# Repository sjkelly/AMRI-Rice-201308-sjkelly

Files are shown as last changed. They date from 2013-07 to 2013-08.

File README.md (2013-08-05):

#AMRI @ Rice University, August 2013
This is a git repository to act as my lab notebook for my fellowship at the Advanced Manufacturing Research Institute at Rice University from August 1st to the 31st. My mentors and sponsors are professor Jordan Miller, Rice University, and Johnny Russell, UltiMachine.

## Design analysis
* [Retrosynthetic Analysis](./retrosynthetic_analysis.md)

## Inkshield Notes
Documentation describing the software exploration of the Inkshield and HPC6602 inkjet head. Also includes notes on Marlin integration.
* [Link](./inkshield_notes.md)

## Daily Objectives
My notes from morning and afternoon meetings with AMRI mentors and fellows. Briefly describes structure of experiments for the day and general objectives/housekeeping.
* [Link](./daily_objectives.md)

## Proposal
The project proposal.
* [Link](./proposal.md)

##License
All software, hardware, and documentation, unless otherwise noted is available under the MIT license. See LICENSE for details.

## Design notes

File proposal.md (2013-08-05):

#Proposal
A project proposal for the Advanced Manufacturing Research Institute.

##Objective
Experiment with convergence of ink jet print head technology and RepRap software and hardware.

##Project Outline
The goal of this project is to improve upon ink jet printing with RepRap technologies for use in the research and the DIY levels. We will achieve this by using existing open source software and hardware as the basis. The scientific method will be used throughout the process, along with an open lab notebook published to GitHub. This will ensure in the event all goals are not attained, useful data will be available to the Internet community, in the form of Git repositories.
###Hardware integration
The first stage of the project will be the integration of ink jet print heads with RepRap mechanics. This will require design of adapters to mount the ink jet heads in place of (or besides) a RepRap extrusion nozzle.
###Software integration
In order to achieve integration with RepRap software, I will focus on contributing to existing projects as much as possible. On the control side of the RepRap, we can leverage Marlin as a development base. On the host side, it will be necessary to build software to handle generation of nozzle firing sequences.
###Electronics Integration
UltiMachine has funded the purchase of 6 InkShields and 11 ink jet heads for this project. I will use RAMBo as a controller base, but design all software to be applicable to any controller with enough extra output pins.

##Existing Solutions

##Applications

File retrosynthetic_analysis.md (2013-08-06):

#Retrosynthetic Analysis
Jordan Miller introduced me to this technique. The wikipedia [page](http://en.wikipedia.org/wiki/Retrosynthetic_analysis) describes it as "a technique for solving problems in the planning of organic syntheses. This is achieved by transforming a target molecule into simpler precursor structures without assumptions regarding starting materials."

##Diagram
In this diagram orange boxes represent our basis for experimentation. Blue boxes represent our decisions. Light green diamonds represent decisions, and the neon green box is the objective.
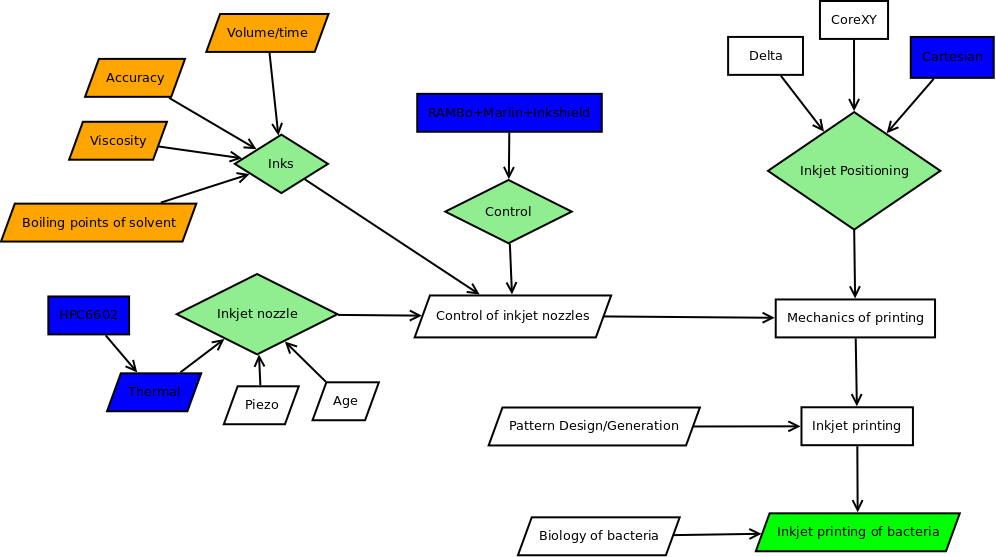
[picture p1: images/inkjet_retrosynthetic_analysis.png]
Retrosynthetic analysis diagram


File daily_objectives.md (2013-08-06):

# 2013-08-06

## Point analysis
The scanner will be here today, so I will be able to test my droplet analysis scripts.
The focus will be on using the printer to generate some output we can scan and quantify. If proven useful I will document the scripts, and begin designing potential experiments around variations in motion and timing.
### Ideas for experiments
* How accurate is the placement of the droplets?
* How does speed influence shape?
* How does pausing influence shape?
* How does pulse timing affect size?

I will use hexagonal droplet patterns to test this as they will have a good balance between spread and density.

# 2013-08-05

## Point analysis
### Goal
Simulation based experiment to quantitatively measure droplet position and shape accuracy.
### Quantify
* Circularity
* Ellipsoid function (momentum)
* Thresholding
* Positioning (gantry positioning and nozzle inaccuracies)
### Experiment
We will generate sample output using an image editor. The samples will be of ideal and poor output. OpenCV or ImageJ will be used to quantify these images computationally.

## Supplies
* Slides and cover slips
* Filter paper
* Vacuum table

## AMRI maintenance
* Email Matt about laser cutter training
* AMRI Google group mailing list

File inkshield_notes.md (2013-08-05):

#Inkshield Notes
This is my log book for experimenting with the [Inkshield][inkshield] by Nicholas C Lewis.

##Goals and initial thoughts
My goal is to integrate inkshield printing capabilities with Marlin. The rational for integration is both technical and social. There is a very large community using, and contributing to, Marlin. As a firm believer in Linus' Law (many eyes make all bug shallow), this will give us a very good code base and potential for long term contribution.

There were of two potential methods of integration with Marlin. The first is to make a move, and specify a stream of nozzle firings on the ink jet for that move. This is much more complicated to integrate with the move planner and adds overhead. We would need to process a stream of data during the move. It would also be difficult to integrate this with gcode, as the gcode command length is limited in size. This would mean movements and printing stream would be decoupled.
My second proposal is to execute a move and fire the nozzles upon arrival (using a new Mcode). This will decrease 'smoothness' of the printing, and create larger files as each nozzle firing needs an associated position. However, implementation is simpler and the options for expandability should be wider. We should also be able to leverage existing tool change functionality in some way.

Each point generated by the inkshield will require a bit. With 12 nozzles, this requires two bytes. Across a print this is a large amount of data. Streaming from an SD card, will manage the bandwidth better than serial over USB.

##Preprocess (Host)
Drawing from the [DIY inkjet printer][diy_inkjet], we will try and convert a BMP into a series of Gcode moves. We can associate a color range with each inkjet head in the case we have multiples.

##Source code for Inkshield
###Initial impressions
After browsing the [source code][inkshield_github] for the inkshield, I believe there is much potential for contribution.
The inkshield library shows two things.
* There is redundant code
* There are constraints on operation which are not necessary.

[The inkshield operates by writing 4 bits to address a nozzle.][inkshield_theory] The pulse pin then triggers the nozzle firing. The redundant code lies in the selection of the pulse pin. Each pulse pin is implemented as a discrete function, rather than a function taking the pulse pin as the argument. This will allow us to distill the 12 functions into one function, that can use any arbitrary pin. This will aid in our goal of controller agnostic software.

Next, the addressing of the nozzle does not need to be constrained to a single port. In theory we are extending the time required to address the nozzle by a factor of four. Nothing constrains us to addressing a nozzle instantaneously. We can take as long as we would like and still achieve the same result. We are however limited by addressing and firing too fast. There needs to be a 0.5us delay between nozzle firings, so individual pin writes will help our safety margin on top of the 0.7us loop overhead. Along with this, we cannot fire the nozzles more than once every 800us. My experiment will be to distill the current inkshield library into a single function, taking 5 pins as arguments and a 16 bit integer as the 6th. 
The first 4 pins will be for addressing the nozzles. The 5th pin will be the pulse pin. The 16 bit integer will represent which nozzles to fire. We will only use the first 12 bits, with 1 representing a firing of the nozzle and 0 representing a pass.

###Inkshield Class
After expanding these notes, it became obvious that there needs to be some sort of instance of an inkshield. Primarily to keep track of the last nozzle firing. It might be advantageous to use a class with pins declared at instantiation with a member to keep track of the last nozzle firing time. The single method will take the 16 bit integer and return 0 for completion of the firing, or 1 if it is requested to fire too soon.

###Experimental improvements
I am using the "I3Inkshield" Arduino sketch as a basis. I began by modifying the spray_ink method to address multiple pins. "fastio.h" was used from Marlin to provide fast write macros. The addressing was done as follows. 
```C
if(i & 1<<0) 
    WRITE(INK_PINA, 1);
if(i & 1<<1)
    WRITE(INK_PINB, 1);
if(i & 1<<2)
    WRITE(INK_PINC, 1);
if(i & 1<<3)
    WRITE(INK_PIND, 1);
```
"i" is the nozzle number we are addressing. This will write the i value as a 4 bit number represented as logic high pin values. The entire function is shown below, where "INK_*" is a global pin definition.
```C
void spray_ink(uint16_t strip)
{
  //loop through the nozzles
  for(uint8_t i = 0; i <= 11; i++){
    //See if nozzle is set to fire
    if(strip & 1<<i){
      
      //Write the nozzle number to the pin shield as 4 bits
      if(i & 1<<0) 
        WRITE(INK_PINA, 1);
      if(i & 1<<1)
        WRITE(INK_PINB, 1);
      if(i & 1<<2)
        WRITE(INK_PINC, 1);
      if(i & 1<<3)
        WRITE(INK_PIND, 1);
        
      //Fire the Nozzle
      WRITE(INK_PULSE, 1); 
      delayMicroseconds(5);
    
      //Set everything low  
      WRITE(INK_PULSE, 0);
      WRITE(INK_PINA, 0);
      WRITE(INK_PINB, 0);
      WRITE(INK_PINC, 0);
      WRITE(INK_PIND, 0);
    }
  }
  //wait to be sure we don't try to fire nozzles too fast and burn them out
  delayMicroseconds(800);
}
```
In hindsight, this implementation might integrate better with Marlin than a class, as ```#define <PIN_NAME>``` is the most common way of declaring pins. We will however need to remove the ```delayMicroseconds(800)``` as this function should block as little as possible. At this stage of the project we have an understanding of inkshield function, and a very basic and portable example Arduino sketch. The sketch and files can be found in [I3InkShield](./I3InkShield). They are available under the LGPL-2.1.

##Marlin integration notes
In order to integrate inkjet head control into Marlin, we will need a new M code. I have decided to start using the M700+ space as it is vacant and would allow expansion as we add new inkjet related mcodes. However, this may change.
The current implementation uses the same method as the I3InkShield sketch for control, adding a provision for multiple inkjet heads. The changes can be seen [here](https://github.com/sjkelly/Marlin/commit/c0dcb9d726e0e034a6c4905d767b1eea17674e17). Currently we need to send a 'M400' to ensure the move is completed before firing the heads. I am looking into how we can do this in the move buffer for smoother printing.

##References
* [DIY Inkjet Printer - University of Washington][diy_inkjet]
[diy_inkjet]: http://thingiverse-production.s3.amazonaws.com/assets/b4/c4/52/58/94/DIY_Inkjet_Printer.pdf 
* [InkShield][inkshield]
[inkshield]: http://nicholasclewis.com/projects/inkshield/
* [InkShield Theory][inkshield_theory]
[inkshield_theory]: http://nicholasclewis.com/projects/inkshield/theory/
* [InkShield GitHub][inkshield_github]
[inkshield_github]: https://github.com/NicholasCLewis/InkShield "InkShield GitHub"

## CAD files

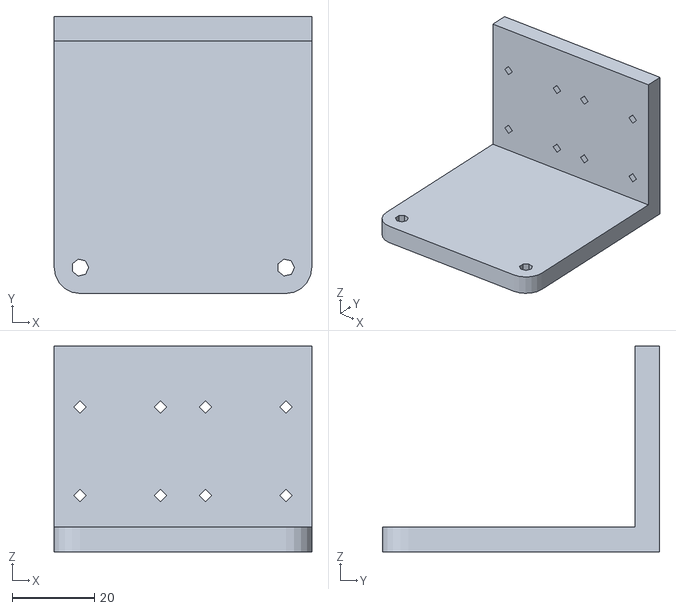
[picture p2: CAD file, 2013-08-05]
hardware/mendel90_hpc6602_carrier_mount/mount.stl
62.6 x 67.3 x 50.0

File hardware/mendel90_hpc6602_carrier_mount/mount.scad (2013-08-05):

include <Magpie/magpie.scad>;

ink_spacing_x = 19.5;
ink_spacing_y = 21.5;
ink_hole_dia = 2;
ink_hole_height = 14.8; // from bottom
ink_carrier_width = 30.5;

mount_hole_dia = 4.2;
mount_hole_wall = mount_hole_dia*1.5;
mount_hole_spacing = 50;
mount_extension = 55;
mount_thickness = 6;
mount_height = 50;



difference()
	{
	union()
	{
		hull()
		{
			cylinder(r=mount_hole_wall, h=mount_thickness);
			translate([mount_hole_spacing, 0, 0])
				cylinder(r=mount_hole_wall, h=mount_thickness);
		}
		translate([-mount_hole_wall, 0, 0])
			cube([mount_hole_spacing+mount_hole_wall*2, mount_extension, mount_thickness]);
		translate([-mount_hole_wall, mount_extension, 0])
			cube([mount_hole_spacing+mount_hole_wall*2, mount_thickness, mount_height]);
	}
	translate([0, 0, -eta])
		cylinder(r=mount_hole_dia/2, h=mount_thickness+eta*2);
	translate([mount_hole_spacing, 0, -eta])
		cylinder(r=mount_hole_dia/2, h=mount_thickness+eta*2);
	for(i=[-1, 1])translate([ink_carrier_width/2*i, 0, 0]){
		//we go upside down
		translate([mount_hole_spacing/2+ink_spacing_x/2, mount_extension-eta, mount_height-ink_hole_height])
			rotate([-90, 0, 0])poly_cylinder(r=ink_hole_dia/2, h=mount_thickness+eta*2);

		translate([mount_hole_spacing/2-ink_spacing_x/2, mount_extension-eta, mount_height-ink_hole_height])
			rotate([-90, 0, 0])poly_cylinder(r=ink_hole_dia/2, h=mount_thickness+eta*2);

		translate([mount_hole_spacing/2+ink_spacing_x/2, mount_extension-eta, mount_height-ink_hole_height-ink_spacing_y])
		rotate([-90, 0, 0])poly_cylinder(r=ink_hole_dia/2, h=mount_thickness+eta*2);

		translate([mount_hole_spacing/2-ink_spacing_x/2, mount_extension-eta, mount_height-ink_hole_height-ink_spacing_y])
			rotate([-90, 0, 0])poly_cylinder(r=ink_hole_dia/2, h=mount_thickness+eta*2);	
	}
}

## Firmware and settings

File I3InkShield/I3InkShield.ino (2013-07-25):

/*
 *  I3InkShield.ino - Basic InkShield text sketch
 *  Copyright 2011, Nicholas C Lewis, GNU Lesser General Public License
 *  http://nicholasclewis.com/inkshield/
 *
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
 *  You should have received a copy of the GNU Lesser General Public
 *  License along with this library; if not, write to the Free Software
 *  Foundation, Inc., 51 Franklin Street, Fifth Floor, Boston, MA  02110-1301  USA
 */
#include "fastio.h"

#ifndef CRITICAL_SECTION_START
  #define CRITICAL_SECTION_START unsigned char _sreg = SREG; cli();
  #define CRITICAL_SECTION_END SREG = _sreg;
#endif //CRITICAL_SECTION_START

#define INK_PINA 7
#define INK_PINB 6
#define INK_PINC 5
#define INK_PIND 4
#define INK_PULSE 2

//initialize data (font) table - each letter is 12 rows
const int rowsPerChar = 12;

//table is 14 letters long
const int numOfChar = 14;
const int fontSize = numOfChar*rowsPerChar;

//"I <3 InkShield" stored in an array
const uint16_t font[fontSize] = {
// 'I'
0b0000000000000000,
0b0000000000000000,
0b0000110000000011,
0b0000110000000011,
0b0000110000000011,
0b0000111111111111,
0b0000111111111111,
0b0000110000000011,
0b0000110000000011,
0b0000110000000011,
0b0000000000000000,
0b0000000000000000,
// 'Space'
0b0000000000000000,
0b0000000000000000,
0b0000000000000000,
0b0000000000000000,
0b0000000000000000,
0b0000000000000000,
0b0000000000000000,
0b0000000000000000,
0b0000000000000000,
0b0000000000000000,
0b0000000000000000,
0b0000000000000000,
// '<'
0b0000000000000000,
0b0000000000000000,
0b0000000000000000,
0b0000000001000000,
0b0000000011100000,
0b0000000110110000,
0b0000001100011000,
0b0000011000001100,
0b0000010000000100,
0b0000000000000000,
0b0000000000000000,
0b0000000000000000,
// '3'
0b0000000000000000,
0b0000001000000100,
0b0000011000000110,
0b0000110000000011,
0b0000110001100011,
0b0000100001100001,
0b0000100001100001,
0b0000110011110011,
0b0000110011110011,
0b0000011110011110,
0b0000001100001100,
0b0000000000000000,
// 'Space'
0b0000000000000000,
0b0000000000000000,
0b0000000000000000,
0b0000000000000000,
0b0000000000000000,
0b0000000000000000,
0b0000000000000000,
0b0000000000000000,
0b0000000000000000,
0b0000000000000000,
0b0000000000000000,
0b0000000000000000,
// 'I'
0b0000000000000000,
0b0000000000000000,
0b0000110000000011,
0b0000110000000011,
0b0000110000000011,
0b0000111111111111,
0b0000111111111111,
0b0000110000000011,
0b0000110000000011,
0b0000110000000011,
0b0000000000000000,
0b0000000000000000,
// 'n'
0b0000000000000000,
0b0000000111111111,
0b0000000111111111,
0b0000000011000000,
0b0000000010000000,
0b0000000110000000,
0b0000000110000000,
0b0000000110000000,
0b0000000110000000,
0b0000000011111111,
0b0000000001111111,
0b0000000000000000,
// 'k'
0b0000000000000000,
0b0000111111111111,
0b0000111111111111,
0b0000000000100000,
0b0000000001100000,
0b0000000011110000,
0b0000000110011000,
0b0000000100001100,
0b0000000000000110,
0b0000000000000011,
0b0000000000000001,
0b0000000000000000,

// 'S'
0b0000000000000000,
0b0000001100001100,
0b0000011110001110,
0b0000010011000010,
0b0000110011000011,
0b0000100001100001,
0b0000100001100001,
0b0000110000110011,
0b0000010000110010,
0b0000011100011110,
0b0000001100001100,
0b0000000000000000,
// 'h'
0b0000000000000000,
0b0000111111111111,
0b0000111111111111,
0b0000000011000000,
0b0000000110000000,
0b0000000110000000,
0b0000000110000000,
0b0000000110000000,
0b0000000110000000,
0b0000000011111111,
0b0000000001111111,
0b0000000000000000,
// 'i'
0b0000000000000000,
0b0000000000000000,
0b0000000000000000,
0b0000000000000000,
0b0000000000000011,
0b0000110011111111,
0b0000110111111111,
0b0000000000000011,
0b0000000000000000,
0b0000000000000000,
0b0000000000000000,
0b0000000000000000,
// 'e'
0b0000000000000000,
0b0000000001111100,
0b0000000011111110,
0b0000000110110011,
0b0000000110110011,
0b0000000110110011,
0b0000000110110011,
0b0000000110110011,
0b0000000110110011,
0b0000000111110110,
0b0000000011100100,
0b0000000000000000,
// 'l'
0b0000000000000000,
0b0000000000000000,
0b0000000000000000,
0b0000000000000000,
0b0000000000000000,
0b0000111111111111,
0b0000111111111111,
0b0000000000000011,
0b0000000000000000,
0b0000000000000000,
0b0000000000000000,
0b0000000000000000,
// 'd'
0b0000000000000000,
0b0000000001111100,
0b0000000011111110,
0b0000000110000011,
0b0000000110000011,
0b0000000110000011,
0b0000000110000011,
0b0000000110000011,
0b0000000110000011,
0b0000111111111111,
0b0000111111111111,
0b0000000000000000,

};

//initialize shield on pin 2

void setup()
{
  SET_OUTPUT(INK_PINA);
  SET_OUTPUT(INK_PINB);
  SET_OUTPUT(INK_PINC);
  SET_OUTPUT(INK_PIND);
  SET_OUTPUT(INK_PULSE);

  //loop 20 times (to print "I <3 InkShield" 20 times)
  for(int i=0;i<20;i++){
    //loop through the array
    for(int i=0; i<fontSize; i++) {
      spray_ink(font[i]);
    }
  //wait so there is some room between prints
  delay(100);
  }
}


void loop()
{

}

void spray_ink(uint16_t strip)
{
  //loop through the nozzles
  for(uint8_t i = 0; i <= 11; i++){
    //See if nozzle is set to fire
    if(strip & 1<<i){

      //Write the nozzle number to the pin shield as 4 bits
      if(i & 1<<0) 
        WRITE(INK_PINA, 1);
      if(i & 1<<1)
        WRITE(INK_PINB, 1);
      if(i & 1<<2)
        WRITE(INK_PINC, 1);
      if(i & 1<<3)
        WRITE(INK_PIND, 1);

      //Fire the Nozzle
      WRITE(INK_PULSE, 1); 
      delayMicroseconds(5);

      //Set everything low  
      WRITE(INK_PULSE, 0);
      WRITE(INK_PINA, 0);
      WRITE(INK_PINB, 0);
      WRITE(INK_PINC, 0);
      WRITE(INK_PIND, 0);
    }
  }
  //wait to be sure we don't try to fire nozzles too fast and burn them out
  delayMicroseconds(800);
}

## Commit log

2013-08-05 add hpc6602 mount for mendel 90
    [mount.scad, mount.stl]
2013-08-05 notes on marlin integration
2013-08-06 some samples for the script

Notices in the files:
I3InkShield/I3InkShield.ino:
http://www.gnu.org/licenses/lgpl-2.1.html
